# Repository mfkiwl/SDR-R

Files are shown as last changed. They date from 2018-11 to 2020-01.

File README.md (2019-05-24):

# SDR-R
Software Defined Radio Receiver(SDR-R) for UMBC Computer Engineering Capstone FA18-SP19

The purpose of this repository will be for tracking of source code changes/additions and team collaboration for the development of this SDR-R. This will facilitate in project organization and documentation.

__Note__: [The home for this repository can be found here](https://github.com/carrera1/SDR-R)

## Directories

__fpga-src/__

Source code for any/all HDL written for the FPGA.

__hw__

Directory for all files related to hardware

__sw-src/__

Source code for any/all C/C++, Matlab/Simulink, or Python code generated.

__vm-info/__

Relevant documentation pertaining to the software development environment is kept here (i.e. list of needed packages). 
This directory also includes an important readme file for setting up important dependencies on your machine. The code 
provided in **sw-src** should function on unix/linux style machines (to include macOS), as long as the relevant dependencies 
are available (mainly pthreads, libftdi, and libusb).

## Set up and Installation

__FPGA__

For any future capstone groups looking back on this, we apologize that the **fpga-src** directory is one of the less organized 
of the bunch. Of the blocks utilized, all but the Xilinx IP cores are here in this repository. These IP cores include a 
clock generator (which should be simple to set up) and a FIFO for interfacing the Rader ("link") block with the FSM 
handling the interfacing with the FTDI chip. The FPGA->FTDI FIFO should have a write width of 16 and a read width of 8. 
The FTDI->FPGA FIFO is written by use for handling the messages sent from the host computer to the FPGA. It is **not** meant 
for interfacing with the Rader block.

__Software__

Instructions for setting up your development environment can be found in **vm-info**. Please, follow the instructions there 
for setting up many of the minor dependencies needed for this project before continuing here.

This project has 2 major dependencies (each with their own sub-dependencies) that are critical for functionality:

* GNU Radio
  - Instructions for setting up found in **vm-info** directory
* libftdi
  - Open source library for writing code the interact with the FT232H bridge we're utilizing
  - Requires **libusb 1.0**, please install this on your system prior to installing libftdi
  - Requires **libconfuse**, please install this on your system prior to installing libftdi

### Installing libftdi

```bash
git://developer.intra2net.com/libftdi
cd libftdi
# READ THE READMEs IN YOUR FAVORITE TEXT EDITOR
```

The libftdi developers included *verbose* instructions within the repository you just cloned. Please read them thoroughly. 
They also include numerous examples demonstrating the functionality of the library, where this project drew heavily from the **stream-test.c**.

The libftdi developers also have their documentation available online which you may find necessary to understand how each 
function works and what their return values may be. [To save you time, you may find it here!](https://www.intra2net.com/en/developer/libftdi/documentation/group__libftdi.html)

Once both GNU Radio and libftdi are installed, software side set up is done. If the FPGA is properly set up, then you're good 
to compile and run the code found in **sw-src**.

## Acknowledgements

This project wouldn't be what it is without the inspiration drawn from the following:
* [This blog post](https://digibird1.wordpress.com/adc-readout-and-usb2-0-data-transfer-with-an-fpga/) for inspiring us to try out an FTDI chip instead of terrible terrible UART.
* [This github repo](https://github.com/RandomReaper/pim-vhdl) for providing an open source FSM for interfacing with the FT232H. Many thanks to [Mssr. Marc Pignat](https://github.com/RandomReaper)!

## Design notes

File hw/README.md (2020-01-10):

# Hardware Directory

All relevant files or documentation related to hardware should be kept here.

Please keep arrangement neat and logical for the sake of other people's sanity

When convenient or necessary, document this readme to explain the organization of this subdirectory

See other readmes as an example for consistant formatting

## Directories

__SDRR__

KiCad design files

__Chips__

Downloaded library files for IC's in schematic

__Datasheets__

Data sheets for the IC's

__FAB__

Output files from PCB design, for fabrication

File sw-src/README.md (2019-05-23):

# Software Source Directory

Source code for anything software related belongs here.
Please keep arrangement neat and logical for the sake of other people's sanity

When convenient or necessary, document this readme to explain the organization of this subdirectory

## About

__Interacting with SDR-R via USB__

The SDR-R is implemented on the Digilent cmod-a7 FPGA dev. board. Communication with host computer
is accomplished via an FTDI FIFO interface, specifically the FT232H in FT245 Synchronous FIFO mode.
 This project particularly uses the UM232H-B, however similar results could easily be had by using 
 any sort of FT232H based solution. The FT2232H would also be a viable alternative.

 Note that interacting with the SDR-R from the host computer will involve utilizing the open-source 
 libftdi libraries. Installation instructions may be provided in the future.
 Otherwise... google is a valuable tool.

## Directories

__demo-code__

The code contained here is effectively what was used for our final demo to 
Dr. LaBerge.

__maindriver__

The code contained here is what we consider our final driver code for this
project. Within this directory is the gnuradio flowgraph (.grc file) that
can be modified with added functionality by opening it in gnuradio-companion.
* compile.sh
  - idiot proof script for compiling the main driver code.
* flowgraph.grc
  - can be modified for added functionality by opening in gnuradio-companion
* INSTRUCTIONS.md
  - contains compilation instructions
* sdrdriver.c
  - main driver code. Requires libftdi, libusb, pthreads, among other things. 
  - Responsible for coordinating data transfer to/from the FTDI chip.
  - Creates a named pipe in /tmp/ during operation for holding IQ samples, this named pipe is removed when program closes.
  - **NOTE** There is a known race condition where the cleanup thread fails to terminate because the write operation which fills the named pipe is not successfully interrupted. Fortunately, if this occurs a simple Ctrl+C will send a second interrupt that will allow the program to close gracefully.
* top_block.py
  - This python script makes up the compiled gnuradio flowgraph. It is called as a child thread by the main driver.

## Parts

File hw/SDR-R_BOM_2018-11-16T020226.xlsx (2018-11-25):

Index | Quantity | Part Number | Manufacturer Part Number | Description | Customer Reference | Available | Backorder | Unit Price | Extended Price USD
1 | 3 | 296-35235-1-ND | ADC1175CIMTCX/NOPB | IC ADC 8BIT 20MHZ 85MW 24-TSSOP |  | 3 | 0 | 3 | 9.00
2 | 3 | SAM1121-32-ND | SSA-132-S-G | CONN RCPT .100" 32POS GOLD PCB |  | 3 | 0 | 5.04 | 15.12
3 | 3 | A97569-ND | 5-1634513-1 | CONN BNC JACK R/A 50 OHM PCB |  | 3 | 0 | 3.4 | 10.20
4 | 1 | 1286-1129-ND | 410-328 | BOARD CMOD A7-15T FPGA 48DIP |  | 1 | 0 | 75 | 75.00
5 | 10 | 311-49.9FRCT-ND | RC1206FR-0749R9L | RES SMD 49.9 OHM 1% 1/4W 1206 |  | 10 | 0 | 0.082 | 0.82
6 | 24 | 445-175206-1-ND | MLF2012A2R2JT000 | FIXED IND 2.2UH 50MA 500 MOHM |  | 24 | 0 | 0.223 | 5.35
7 | 10 | 1276-6330-1-ND | CIM21J202NE | FERRITE BEAD 2 KOHM 0805 1LN |  | 10 | 0 | 0.03 | 0.30
8 | 10 | 445-173302-1-ND | FG20X7S1H106KRT06 | CAP CER 10UF 50V X7S RADIAL |  | 10 | 0 | 0.975 | 9.75
9 | 3 | 296-18593-1-ND | SN74LVC8T245PWR | IC TRNSLTR BIDIRECTIONAL 24TSSOP |  | 3 | 0 | 1.05 | 3.15
10 | 3 | 296-16844-1-ND | SN74LVC1T45DCKR | IC TRNSLTR BIDIRECTIONAL SC70-6 |  | 3 | 0 | 0.6 | 1.80
11 | 3 | DESD5V0U1BA-7DICT-ND | DESD5V0U1BA-7 | TVS DIODE 5V 7.2V SOD323 |  | 3 | 0 | 0.29 | 0.87
12 | 100 | 445-14483-1-ND | C2012X6S1C106K085AC | CAP CER 10UF 16V X6S 0805 |  | 100 | 0 | 0.1466 | 14.66
13 | 10 | 1276-2589-1-ND | CL21C151GBANNNC | CAP CER 150PF 50V C0G/NP0 0805 |  | 10 | 0 | 0.16 | 1.60
14 | 3 | 1276-1305-1-ND | CL21C620JBANNNC | CAP CER 62PF 50V C0G/NP0 0805 |  | 3 | 0 | 0.1 | 0.30
15 | 10 | 311-110CRCT-ND | RC0805FR-07110RL | RES SMD 110 OHM 1% 1/8W 0805 |  | 10 | 0 | 0.047 | 0.47
16 | 3 | 987-1155-ND | 84WR10KLF | TRIMMER 10K OHM 0.25W SMD TOP |  | 3 | 0 | 2.54 | 7.62
17 | 10 | 1276-2698-1-ND | CL21C911JBCNNNC | CAP CER 910PF 50V C0G/NP0 0805 |  | 10 | 0 | 0.142 | 1.42
18 | 10 | 732-7857-1-ND | 885012007062 | CAP CER 680PF 50V C0G/NP0 0805 |  | 10 | 0 | 0.07 | 0.70
19 | 1 | SMDTCLF-ND | SMDTCLF | SOLDER TIP TINNER (ACTIVATOR) |  | 1 | 0 | 7.65 | 7.65
20 | 1 | TS391LT-ND | TS391LT | THERMALLY STABLE SOLDER PASTE NO |  | 1 | 0 | 16.95 | 16.95
21 | 3 | 296-26279-1-ND | OPA354AIDBVR | IC OPAMP VFB 100MHZ RRO SOT23-5 |  | 3 | 0 | 1.87 | 5.61
22 | 10 | LM2766M6X/NOPBCT-ND | LM2766M6X/NOPB | IC REG SWITCHD CAP 2VIN SOT23 |  | 10 | 0 | 0.912 | 9.12
23 | 100 | 399-1177-1-ND | C0805C104Z5VACTU | CAP CER 0.1UF 50V Y5V 0805 |  | 100 | 0 | 0.0289 | 2.89
24 | 3 | B120-FDICT-ND | B120-13-F | DIODE SCHOTTKY 20V 1A SMA |  | 3 | 0 | 0.37 | 1.11
25 | 3 | 296-27139-5-ND | UA78M05IDCY | IC REG LINEAR 5V 500MA SOT223-4 |  | 3 | 0 | 0.62 | 1.86
26 | 3 | 296-27140-5-ND | UA78M33CDCY | IC REG LIN 3.3V 500MA SOT223-4 |  | 3 | 0 | 0.58 | 1.74
27 | 3 | 493-10109-1-ND | UZR1C470MCL1GB | CAP ALUM 47UF 20% 16V SMD |  | 3 | 0 | 0.7 | 2.10
28 | 10 | 311-270CRCT-ND | RC0805FR-07270RL | RES SMD 270 OHM 1% 1/8W 0805 |  | 10 | 0 | 0.046 | 0.46
29 | 10 | 311-10KARCT-ND | RC0805JR-0710KL | RES SMD 10K OHM 5% 1/8W 0805 |  | 10 | 0 | 0.04 | 0.40

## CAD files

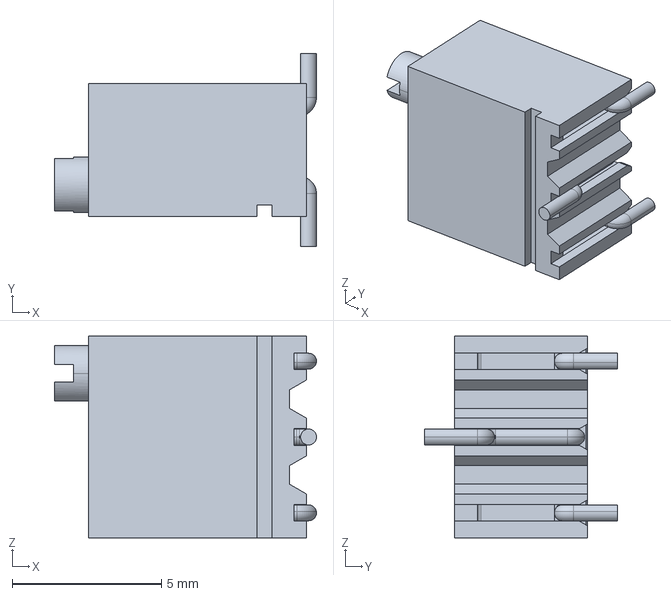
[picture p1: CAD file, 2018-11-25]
hw/Chips/84w.stp
8.78 x 6.48 x 6.76 mm

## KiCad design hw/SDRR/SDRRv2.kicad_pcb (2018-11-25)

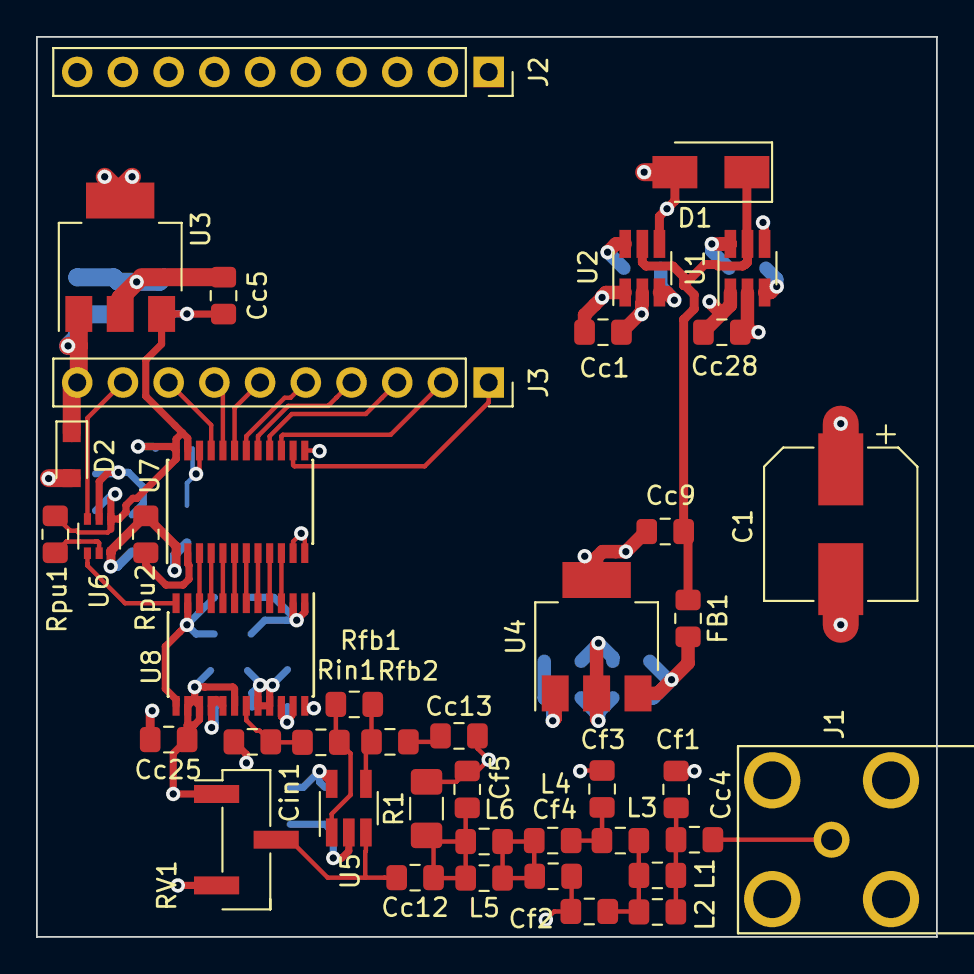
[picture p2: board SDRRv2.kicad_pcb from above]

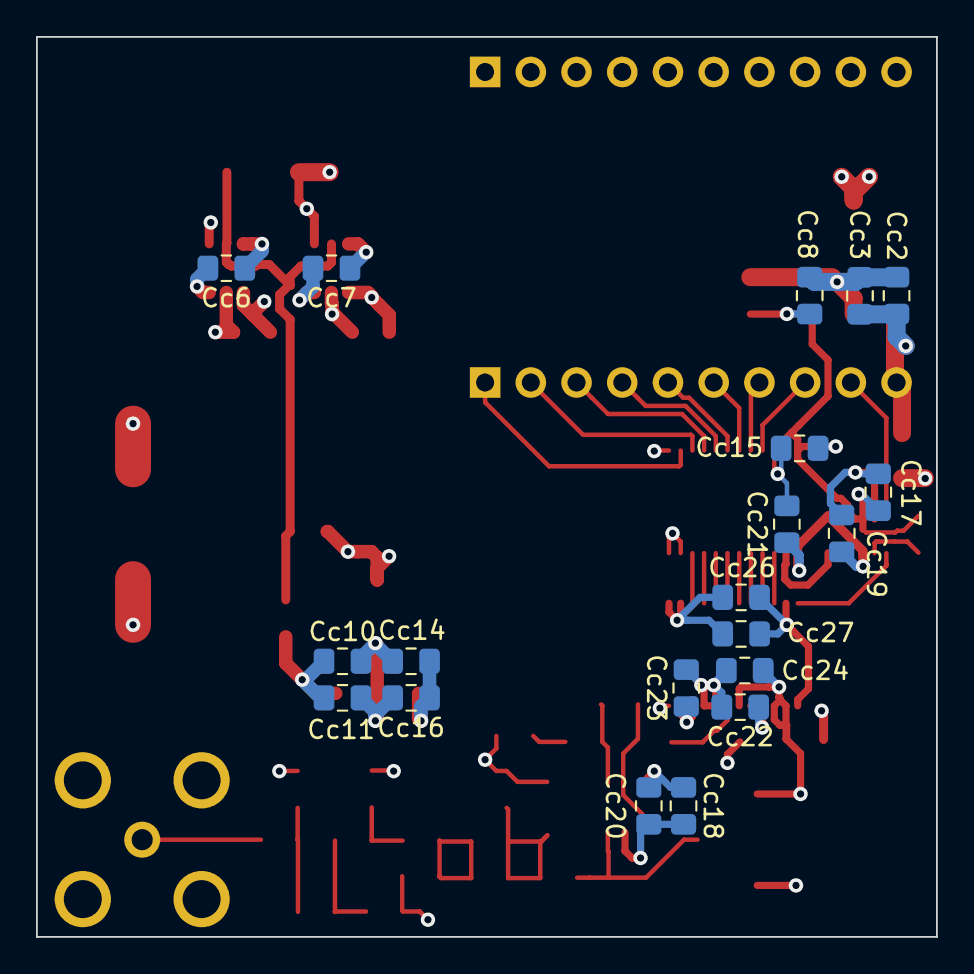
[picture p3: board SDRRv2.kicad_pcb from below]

Board: 4 copper layers, 50.0 x 50.0 mm, 62 parts (20 on the bottom side), 43 nets.

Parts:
C1: 47u; CP_Elec_8x6.2
Cc1, Cc3, Cc4, Cc5, Cc6, Cc7, Cc9, Cc10, Cc12, Cc13, Cc14, Cc15, Cc17, Cc18, Cc19, Cc21, Cc25, Cc27, Cc28: 10u; C_0805_2012Metric_Pad1.15x1.40mm_HandSolder
Cc2, Cc8, Cc11, Cc16, Cc20, Cc24, Cc26: 0.1u; C_0805_2012Metric_Pad1.15x1.40mm_HandSolder
Cc22, Cc23: 10uF; C_0805_2012Metric_Pad1.15x1.40mm_HandSolder
Cf1, Cf5: 150pF; C_0805_2012Metric_Pad1.15x1.40mm_HandSolder
Cf2, Cf4: 680pF; C_0805_2012Metric_Pad1.15x1.40mm_HandSolder
Cf3: 910pF; C_0805_2012Metric_Pad1.15x1.40mm_HandSolder
Cin1: 62pF; C_0805_2012Metric_Pad1.15x1.40mm_HandSolder
D1: B120-E3; D_SMA
D2: D_TVS; D_SOD-323_HandSoldering
FB1: L_Core_Ferrite; L_0805_2012Metric_Pad1.15x1.40mm_HandSolder
J1: Conn_Coaxial; TE_5-1634513-1
J2, J3: Conn_01x10_Female; PinSocket_1x10_P2.54mm_Vertical
L1, L2, L3, L4, L5, L6: 2.2u; L_0805_2012Metric_Pad1.15x1.40mm_HandSolder
R1: 50; R_1206_3216Metric_Pad1.42x1.75mm_HandSolder
RV1: R_POT; PinHeader_1x03_P2.54mm_Vertical_SMD_Pin1Left
Rfb1, Rfb2: 270; R_0805_2012Metric_Pad1.15x1.40mm_HandSolder
Rin1: 110; R_0805_2012Metric_Pad1.15x1.40mm_HandSolder
Rpu1, Rpu2: 10k; R_0805_2012Metric_Pad1.15x1.40mm_HandSolder
U1, U2: LM2766M6X_NOPB; SOT-23-6_Handsoldering
U3: UA78M33CDCY; SOT-223-3_TabPin2
U4: UA78M05IDCY; SOT-223-3_TabPin2
U5: OPA354AIDBVR; SOT-23-5_HandSoldering
U6: SN74LVC1T45DCK; SOT-363_SC-70-6
U7: SN74LVC8T245PWR; TSSOP-24_4.4x7.8mm_P0.65mm
U8: ADC1173; TSSOP-24_4.4x7.8mm_P0.65mm

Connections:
+3V3: Cc5.1, Cc8.1, Cc15.2, Cc17.1, Rpu1.1, U3.3, U6.1, U7.23, U7.24
+5V: C1.1, Cc1.1, Cc2.1, Cc3.1, Cc19.1, Cc21.1, Cc26.1, Cc27.1, Cc28.1, D1.2, D2.1, J3.10, Rpu2.1, U1.1, U1.4, U2.1, U2.4, U3.1, U6.6, U7.1, U8.11, U8.13
+5VA: Cc14.1, Cc16.1, Cc18.1, Cc20.1, Cc24.2, Cc25.2, RV1.1, U4.1, U5.5, U8.14, U8.15, U8.18
GNDREF: C1.2, Cc1.2, Cc2.2, Cc3.2, Cc5.2, Cc8.2, Cc9.2, Cc10.2, Cc11.2, Cc13.2, Cc14.2, Cc15.1, Cc16.2, Cc17.2, Cc18.2, Cc19.2, Cc20.2, Cc21.2, Cc22.2, Cc23.2, Cc24.1, Cc25.1, Cc26.2, Cc27.2, Cc28.2, Cf1.2, Cf2.2, Cf3.2, Cf4.2, Cf5.2, Cin1.2, D2.2, J1.2, J2.10, R1.2, RV1.3, U1.2, U2.2, U3.2, U4.2, U5.2, U6.2, U7.11, U7.12, U7.13, U7.22, U8.1, U8.2, U8.20, U8.21, U8.24
unnamed: Cc4.1, J1.1
unnamed: Cc4.2, Cf1.1, L1.1, L2.1
unnamed: Cc6.1, U1.6
unnamed: Cc6.2, U1.3
unnamed: Cc7.1, U2.6
unnamed: Cc7.2, U2.3
unnamed: Cc9.1, D1.1, FB1.1, U1.5, U2.5
unnamed: Cc10.1, Cc11.1, FB1.2, U4.3
unnamed: Cc12.1, Cf5.1, L5.2, L6.2, R1.1
unnamed: Cc12.2, RV1.2, U5.3
unnamed: Cc13.1, Rfb2.2
unnamed: Cc22.1, U8.16, U8.17
unnamed: Cc23.1, U8.22, U8.23
unnamed: Cf2.1, L1.2, L2.2, L3.1
unnamed: Cf3.1, L3.2, L4.1
unnamed: Cf4.1, L4.2, L5.1, L6.1
unnamed: Cin1.1, Rin1.2, U8.19
unnamed: J3.1, U7.14
unnamed: J3.2, U7.15
unnamed: J3.3, U7.16
unnamed: J3.4, U7.17
unnamed: J3.5, U7.18
unnamed: J3.6, U7.19
unnamed: J3.7, U7.20
unnamed: J3.8, U7.21
unnamed: J3.9, U6.3
unnamed: Rfb1.1, Rin1.1, U5.1
unnamed: Rfb1.2, Rfb2.1, U5.4
unnamed: Rpu1.2, U6.5
unnamed: Rpu2.2, U7.2
unnamed: U6.4, U8.12
unnamed: U7.3, U8.10
unnamed: U7.4, U8.9
unnamed: U7.5, U8.8
unnamed: U7.6, U8.7
unnamed: U7.7, U8.6
unnamed: U7.8, U8.5
unnamed: U7.9, U8.4
unnamed: U7.10, U8.3

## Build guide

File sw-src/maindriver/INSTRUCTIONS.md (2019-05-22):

# Introduction

The code contained here is intended for the Final Demo.

## Files

* flowgraph.grc
  - This may be edited via gnuradio-companion. When compiled in gnuradio-companion, it will generate top_block.py
* sdrdriver.c
  - This is **the** driver code for this demo.
* top_block.py
  - This is the gnuradio flowgraph that is invoked by sdrdriver

## Compilation Instructions

### Normal Way

```bash
gcc -Wall sdrdriver.c -lftdi1 -pthread -o runme.out
```
### Idiot Proof Way

```bash
./compile.sh
```

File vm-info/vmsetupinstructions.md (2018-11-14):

# Install VBox Additions
__NOTE__ 

The following is specifically instructions for the Debian Linux distribution. 
If you're using Ubuntu or Mint, this will maybe still work since they're based on 
Debian, but I can't promise
```bash
# Switch to root user
$ su
# Update APT database
$ apt-get update
# Then install security updates
$ apt-get upgrade
# Then install the following required packages for Virtualbox Guest Additions
$ apt-get install build-essential module-assistant
# Now configure system for building kernel modules
$ m-a prepare
# Do the Virtualbox thing to insert the guest additions CD
# then either cd as root into /media/cdrom1 or just navigate
# with the file explorer and open a root terminal in the directory
# Once there, run the following command
$ sh VBoxLinuxGuestAdditions.run
```
Pay close attention to the output, if there are any errors, try installing any/all 
of the packages in the following section (some/most should have been installed in 
the previous steps like gcc/g++/make/perl/etc.

After a reboot, you should now have a much better experience with your VM

## Want to SSH in? (Optional)
If you are using Debian and wish to SSH into your guest VM from your host computer:
1. Google how to add a 2nd "host-only" adapter 
2. [Do what they say here](https://unix.stackexchange.com/questions/37122/virtualbox-two-network-interfaces-nat-and-host-only-ones-in-a-debian-guest-on),
 or you may not have access to outside internet
 
## God, the default terminal colors hurt my eyeballs (Optional)
1. Edit -> Profile Preferences
2. In General tab, give your profile a name
3. In Colors tab, uncheck 'Use colors from system theme'
4. Under the same tab, select 'Solarized' from Built-in schemes drop down menu
5. Click ok
6. Edit -> Preferences
7. Click profiles tab, set your sexy profile as default by either deleting any other unnamed profiles, or using the drop down menu. I'm sure you can read.
8. Profit.

# Recommended Packages for Fresh Linux VM
* git
* gcc
* g++
* make
  - makefiles and whatnot
* libelf-dev
  - Required for OS class
* libqt4-dev
  - Needed for standard gui libraries
* libncurses5-dev
* libssl-dev
* perl
  - Needed for some build/compilation scripts
* pkg-config
* python and python-dev
  - 2.7 for GNU Radio, possibly 3 for other things
* pip
  - python package installer. Has loads of gnuradio libraries and is required.
  - May install via apt or [via these instructions](https://pip.pypa.io/en/stable/installing/)
* curl
  - Will be a dependency later on

# Installing GNU Radio

Review GNU radio by reading their Wiki. I'm building it from source *as you probably should too*, but it may
suffice for you to simply install the binaries and libraries via apt.

```bash
$ sudo apt-get install gnuradio
```

__NOTE__

If you install it this way, and end up having issues later on, I'm not going to help you... 
just apt-get remove it, and [install it via its source](https://wiki.gnuradio.org/index.php/InstallingGRFromSource)
like I did.

## Installing GNU Radio from Source

__SIDENOTE1__

GNU Radio currently is still mostly built on old Python 2.7 and is in the process of migrating to Python 3.
Unfortunately, we're not there yet so **make sure you have python and pip installed**.

__SIDENOTE2__

I wrote up the following steps as I completed them, and every step went perfect the first time around. Note that I am using Debian 9.5
as my base operating system. As you should be utilizing a VM... be smart about it all and take advantage of the **snapshots** 
capability that VirtualBox provides. I highly suggest creating one before starting the actual installation process at all.

1. Again, make sure you've installed python and pip. I linked to some instructions earlier, but if you're lazy 
[here they are again](https://pip.pypa.io/en/stable/installing/). Note that running get-pip.py will require root
priveleges or by specifying installing specifically to userspace with the proper '--user' flag.

2. Make sure pip is up to date before proceeding with the install
```bash
# If you previously installed pip with the --user flag,
#  You will have to do that every time you install or upgrade
#  a package you're managing via pip. For me, I would have to
#  prepend all these commands with sudo rather than using the
#  --user flag
$ [sudo] pip install -U pip
```

3. Using pip, we're going to install PyBOMBS. What is PyBOMBS? 
[Click here to find out more](https://www.gnuradio.org/blog/pybombs-the-what-the-how-and-the-why). 
I did a quick read through [of this](https://github.com/gnuradio/pybombs/blob/master/README.md) 
prior to installing, and there's some good stuff. All you really need to know at the moment
is that PyBOMBS is going to do all the heavy lifting for installing GNU Radio but you'll have
more time in a minute to read through it.
```bash
$ [sudo] pip install PyBOMBS
```

4. Once you have PyBOMBS successfully installed:
```bash
# NOTE: The installation process may go more smoothly if you allocate more than
#        two cores to your VM. If this isn't possible, then no worries.

# Apply a configuration (idk the particulars of what this really means)
$ pybombs auto-config
# Add the default recipes
$ pybombs recipes add-defaults
# Install gnuradio into your home directory ~/gr-prefix
$ pybombs prefix init ~/gr-prefix -a myprefix -R gnuradio-default
# Wait for last command to complete... go to the bathroom or something
# Or read the following which explains wth a prefix is
# Then if it's still working after you're done reading... leave your
#  laptop in the capstone lab or something and go to starbucks
# Seriously, it takes forever. If you see 'volk' being downloaded or built,
#  then you're on your last leg of the install
```
  - So what the heck is a prefix? Welp, it's the directory into which packages are installed.
  It may be `~/gr-prefix` like we specified in that last command, but it can be anything really.
  It should reside in your home directory so that it's easy to find and doesn't require admin
  rights to modify. Other developers out there may have multiple prefixes for their projects or w/e
  but we should be able to get by with just one. 
  - Prefixes require a configuration directory to function properly.
  Typically, it is called `.pybombs/` and is a subdirectory of the prefix.
  So, if your prefix is `~/gr-prefix`, there will be a directory called
  `~/gr-prefix/.pybombs/` containing special files. The two most important
  files are the inventory file (inventory.yml) and the prefix-local
  configuration file (config.yml), but it can also contain recipe files
  that are specific to this prefix.
  - Note that I'm not pulling all this info out of my ass, but putting it here for the lazy people
  who didn't click on [the previous link that I'm so kindly linking again](https://github.com/gnuradio/pybombs/blob/master/README.md)

5. Now you can run gnuradio-companion in one of two ways:
  - First set up the environment dictated by the packages installed into your prefix directory, and then run gnuradio-companion
  ```bash
  $ source ~/gr-prefix/setup_env.sh
  $ gnuradio-companion
  ```
  - Or use pybombs which I assume defaults to the default prefix which we specified earlier. I don't personally do it this way
  ```bash
  $ pybombs run gnuradio-companion
  ```
6. You have now installed the base gnuradio package from source!

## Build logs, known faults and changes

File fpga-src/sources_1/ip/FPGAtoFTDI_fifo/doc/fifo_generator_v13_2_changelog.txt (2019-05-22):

2018.2.2:
 * Version 13.2 (Rev. 2)
 * No changes

2018.2.1:
 * Version 13.2 (Rev. 2)
 * No changes

2018.2:
 * Version 13.2 (Rev. 2)
 * No changes

2018.1:
 * Version 13.2 (Rev. 2)
 * Bug Fix: Enable Safety Circuit option was unintentionally made available for user selection when Enable Reset Synchronization is not selected. This unintentional enablement is corrected and Enable Safety Circuit is available for user selection only if Enable Reset Synchronization option is selected
 * Bug Fix: REQP-1839 DRC warning removed from example test bench
 * Bug Fix: Read Data Count in behavioral model is updated to start with a valid value when Enable Reset Synchronization option is not selected
 * Other: As FIFO Generator core uses XPM_CDC module, user must ensure that the wr_rst and rd_rst overlap for at least C_SYNCHRONIZER_STAGE+1 slowest clock cycles if Enable Reset Synchronization option is disabled

2017.4:
 * Version 13.2 (Rev. 1)
 * Revision change in one or more subcores

2017.3:
 * Version 13.2
 * Feature Enhancement: Enable Safety Circuit option is made default for BRAM based FIFOs when Asynchronous Reset is selected
 * Feature Enhancement: All outputs are made synchronous to respective clock domain when Enable Safety Circuit option is selected
 * Feature Enhancement: All outputs are invalid for reset duration + 60 slowest clock cycles when Enable Safety Circuit option is selected
 * Feature Enhancement: All outputs are invalid for reset duration + 30 slowest clock cycles when Enable Safety Circuit option is not selected
 * Feature Enhancement: The outputs of FIFO Generator may be Xs for initial few clock cycles if the core is configured without reset. It is recommended to wait for 15 slowest clock cycles at the beginning of behavioral simulation (from time 0) before accessing the FIFO

2017.2:
 * Version 13.1 (Rev. 3)
 * No changes

2017.1:
 * Version 13.1 (Rev. 3)
 * Bug Fix: FIFO Generator core was constructing the buit-in FIFO sub-optimally for 2K-deep and 36-bit wide configuration. This is corrected to use the optimal FIFO structure
 * Bug Fix: In order to enable the tool to perform the recovery check on the reset, set_false_path for reset is kept only from the input port to the first flop where it connects to
 * Feature Enhancement: Updated the FIFO Generator's constraints to improve tool performance processing its XDC
 * Other: Internal device family change, no functional changes

2016.4:
 * Version 13.1 (Rev. 2)
 * Port Change: None
 * Bug Fix: Supported features table in the first page of GUI updated to reflect the asymmetry support for common clock BRAM FIFO
 * Feature Enhancement: None

2016.3:
 * Version 13.1 (Rev. 1)
 * Port Change: wr_rst_busy and rd_rst_busy ports made available if safety circuit is enabled
 * Bug Fix: Fixed issue which was causing the m_axis_tvalid to go high after the reset is released and no valid data written to the FIFO
 * Feature Enhancement: Safety circuit is made independent of Output Register and Enable Reset Synchronization options
 * Other: Added support for future devices
 * Other: Source HDL files are concatenated into a single file to speed up synthesis and simulation. No changes required by the user

2016.2:
 * Version 13.1
 * No changes

2016.1:
 * Version 13.1
 * Delivering only Verilog behavioral model.
 * Constraint(s) for Independent Clocks Distributed RAM FIFO is changed, which may issue a CDC-1 warning that can be safely ignored.
 * Output Register option is updated to offer either Embedded Register or Fabric Register or Both Embedded and Fabric Registers.
 * Updated the FIFO Generator GUI to provide Embedded Register option for Built-in FIFO when ECC mode in selected.
 * Programmable Full and Programmable Empty Threshold range has been reduced for UltraScale and UltraScale+ Built-in FIFO configurations. For more information on the exact threshold range change, refer the PG(057)
 * Programmable Full and Programmable Empty Threshold values were reset to its default values when the previous version of the core is upgraded to the latest version. This has been corrected

2015.4.2:
 * Version 13.0 (Rev. 1)
 * No changes

2015.4.1:
 * Version 13.0 (Rev. 1)
 * No changes

2015.4:
 * Version 13.0 (Rev. 1)
 * Fixed safety circuit related warnings in Behavioral model

2015.3:
 * Version 13.0
 * Additional safety circuit option provided for asynchronous reset configurations.
 * Delivering only VHDL behavioral model.
 * Added asymmetric port width support for 7-series Common Clock Block RAM FIFO
 * IP revision number added to HDL module, library, and include file names, to support designs with both locked and upgraded IP instances

2015.2.1:
 * Version 12.0 (Rev. 4)
 * No changes

2015.2:
 * Version 12.0 (Rev. 4)
 * No changes

2015.1:
 * Version 12.0 (Rev. 4)
 * Delivering  non encrypted behavioral models.
 * Enabled out-of-context clock frequency setting by adding FREQ_HZ parameter to clock ports
 * Enabling behavioral simulation for Built-in FIFO configurations changes the simulation file names and delivery structure.
 * Supported devices and production status are now determined automatically, to simplify support for future devices

2014.4.1:
 * Version 12.0 (Rev. 3)
 * No changes

2014.4:
 * Version 12.0 (Rev. 3)
 * Reduced DRC warnings.
 * Internal device family change, no functional changes
 * Encrypted source files are concatenated together to reduce the number of files and to reduce simulator compile time

2014.3:
 * Version 12.0 (Rev. 2)
 * Added support for Asynchronous AXI Stream Packet FIFO for UltraScale devices.
 * Added support for write data count and read data count for Asynchronous AXI Stream Packet FIFO for UltraScale devices.
 * Added support for write data count and read data count for Common Clock Block RAM FIFO when Asymmetric Port Width option is enabled for UltraScale devices.
 * Added support for Low Latency Built-in FIFO for UltraScale devices.

2014.2:
 * Version 12.0 (Rev. 1)
 * Repackaged to improve internal automation, no functional changes.

2014.1:
 * Version 12.0
 * Asynchronous reset port (rst) for Built-in FIFO configurations is removed for UltraScale Built-in FIFO configurations. When upgrading from previously released core, 'rst' port will be replaced by 'srst' port.
 * Synchronous reset (srst) mechanism is changed now for UltraScale devices. FIFO Generator will now provide wr_rst_busy and rd_rst_busy output ports. When wr_rst_busy is active low, the core is ready for write operation and when rd_rst_busy is active low, the core is ready for read operation.
 * Added asymmetric port width support for Common Clock Block RAM FIFO, Common Clock Built-in FIFO and Independent Clocks Built-in FIFO configurations for UltraScale Devices
 * Added 'sleep' input port for Common Clock Built-in FIFO and Independent Clocks Built-in FIFO configurations only for UltraScale Devices
 * Internal device family name change, no functional changes

2013.4:
 * Version 11.0 (Rev. 1)
 * Added support for Ultrascale devices
 * Common Clock Builtin FIFO is set as default implementation type only for UltraScale devices
 * Embedded Register option is always ON for Block RAM and Builtin FIFOs only for UltraScale devices
 * Reset is sampled with respect to wr_clk/clk and then synchronized before the use in FIFO Generator only for UltraScale devices

2013.3:
 * Version 11.0
 * AXI ID Tags (s_axi_wid and m_axi_wid) are now determined by AXI protocol type (AXI4, AXI3). When upgrading from previously released core, these signals will be removed when AXI_Type = AXI4_Full.
 * AXI Lock signals (s_axi_awlock, m_axi_awlock, s_axi_arlock and m_axi_arlock) are now determined by AXI Protocol type (AXI4, AXI3). When upgrading from previously released core, these signals width will reduce from 2-bits to 1-bit when AXI_Type=AXI4_Full
 * Removed restriction on packet size in AXI4 Stream FIFO mode. Now, the packet size can be up to FIFO depth
 * Enhanced support for IP Integrator
 * Reduced warnings in synthesis and simulation
 * Added support for Cadence IES and Synopsys VCS simulators
 * Improved GUI speed and responsiveness, no functional changes
 * Increased the maximum number of synchronization stages from 4 to 8. The minimum FIFO depth is limited to 32 when number of synchronization stages is > 4

2013.2:
 * Version 10.0 (Rev. 1)
 * Constraints processing order changed

2013.1:
 * Version 10.0
 * Native Vivado Release
 * There have been no functional or interface changes to this IP.  The version number has changed to support unique versioning in Vivado starting with 2013.1.

(c) Copyright 2002 - 2018 Xilinx, Inc. All rights reserved.

This file contains confidential and proprietary information
of Xilinx, Inc. and is protected under U.S. and
international copyright and other intellectual property
laws.

DISCLAIMER
This disclaimer is not a license and does not grant any
rights to the materials distributed herewith. Except as
otherwise provided in a valid license issued to you by
Xilinx, and to the maximum extent permitted by applicable
law: (1) THESE MATERIALS ARE MADE AVAILABLE "AS IS" AND
WITH ALL FAULTS, AND XILINX HEREBY DISCLAIMS ALL WARRANTIES
AND CONDITIONS, EXPRESS, IMPLIED, OR STATUTORY, INCLUDING
BUT NOT LIMITED TO WARRANTIES OF MERCHANTABILITY, NON-
INFRINGEMENT, OR FITNESS FOR ANY PARTICULAR PURPOSE; and
(2) Xilinx shall not be liable (whether in contract or tort,
including negligence, or under any other theory of
liability) for any loss or damage of any kind or nature
related to, arising under or in connection with these
materials, including for any direct, or any indirect,
special, incidental, or consequential loss or damage
(including loss of data, profits, goodwill, or any type of
loss or damage suffered as a result of any action brought
by a third party) even if such damage or loss was
reasonably foreseeable or Xilinx had been advised of the
possibility of the same.

CRITICAL APPLICATIONS
Xilinx products are not designed or intended to be fail-
safe, or for use in any application requiring fail-safe
performance, such as life-support or safety devices or
systems, Class III medical devices, nuclear facilities,
applications related to the deployment of airbags, or any
other applications that could lead to death, personal
injury, or severe property or environmental damage
(individually and collectively, "Critical
Applications"). Customer assumes the sole risk and
liability of any use of Xilinx products in Critical
Applications, subject only to applicable laws and
regulations governing limitations on product liability.

THIS COPYRIGHT NOTICE AND DISCLAIMER MUST BE RETAINED AS
PART OF THIS FILE AT ALL TIMES.

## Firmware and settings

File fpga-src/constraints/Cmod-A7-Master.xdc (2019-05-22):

## This file is a general .xdc for the CmodA7 rev. B
## To use it in a project:
## - uncomment the lines corresponding to used pins
## - rename the used ports (in each line, after get_ports) according to the top level signal names in the project

## 12 MHz Clock Signal
set_property -dict { PACKAGE_PIN L17   IOSTANDARD LVCMOS33 } [get_ports { sysclk }]; #IO_L12P_T1_MRCC_14 Sch=gclk
create_clock -add -name sys_clk_pin -period 83.33 -waveform {0 41.66} [get_ports {sysclk}];

## LEDs
#set_property -dict { PACKAGE_PIN A17   IOSTANDARD LVCMOS33 } [get_ports { led[0] }]; #IO_L12N_T1_MRCC_16 Sch=led[1]
#set_property -dict { PACKAGE_PIN C16   IOSTANDARD LVCMOS33 } [get_ports { led[1] }]; #IO_L13P_T2_MRCC_16 Sch=led[2]

## RGB LED
#set_property -dict { PACKAGE_PIN B17   IOSTANDARD LVCMOS33 } [get_ports { led0_b }]; #IO_L14N_T2_SRCC_16 Sch=led0_b
#set_property -dict { PACKAGE_PIN B16   IOSTANDARD LVCMOS33 } [get_ports { led0_g }]; #IO_L13N_T2_MRCC_16 Sch=led0_g
#set_property -dict { PACKAGE_PIN C17   IOSTANDARD LVCMOS33 } [get_ports { led0_r }]; #IO_L14P_T2_SRCC_16 Sch=led0_r

## Buttons
set_property -dict { PACKAGE_PIN A18   IOSTANDARD LVCMOS33 } [get_ports { BTNreset }]; #IO_L19N_T3_VREF_16 Sch=btn[0]
set_property -dict { PACKAGE_PIN B18   IOSTANDARD LVCMOS33 } [get_ports { fifo_reset }]; #IO_L19P_T3_16 Sch=btn[1]

## Pmod Header JA
#set_property -dict { PACKAGE_PIN G17   IOSTANDARD LVCMOS33 } [get_ports { Cbus0 }]; #IO_L5N_T0_D07_14 Sch=ja[1]
#set_property -dict { PACKAGE_PIN G19   IOSTANDARD LVCMOS33 } [get_ports { Cbus2 }]; #IO_L4N_T0_D05_14 Sch=ja[2]
#set_property -dict { PACKAGE_PIN N18   IOSTANDARD LVCMOS33 } [get_ports { ja[2] }]; #IO_L9P_T1_DQS_14 Sch=ja[3]
#set_property -dict { PACKAGE_PIN L18   IOSTANDARD LVCMOS33 } [get_ports { ja[3] }]; #IO_L8P_T1_D11_14 Sch=ja[4]
#set_property -dict { PACKAGE_PIN H17   IOSTANDARD LVCMOS33 } [get_ports { ja[4] }]; #IO_L5P_T0_D06_14 Sch=ja[7]
#set_property -dict { PACKAGE_PIN H19   IOSTANDARD LVCMOS33 } [get_ports { ja[5] }]; #IO_L4P_T0_D04_14 Sch=ja[8]
#set_property -dict { PACKAGE_PIN J19   IOSTANDARD LVCMOS33 } [get_ports { ja[6] }]; #IO_L6N_T0_D08_VREF_14 Sch=ja[9]
#set_property -dict { PACKAGE_PIN K18   IOSTANDARD LVCMOS33 } [get_ports { ja[7] }]; #IO_L8N_T1_D12_14 Sch=ja[10]

## Analog XADC Pins
## Only declare these if you want to use pins 15 and 16 as single ended analog inputs. pin 15 -> vaux4, pin16 -> vaux12
#set_property -dict { PACKAGE_PIN G2    IOSTANDARD LVCMOS33 } [get_ports { xa_n[0] }]; #IO_L1N_T0_AD4N_35 Sch=ain_n[15]
#set_property -dict { PACKAGE_PIN G3    IOSTANDARD LVCMOS33 } [get_ports { xa_p[0] }]; #IO_L1P_T0_AD4P_35 Sch=ain_p[15]
#set_property -dict { PACKAGE_PIN J2    IOSTANDARD LVCMOS33 } [get_ports { xa_n[1] }]; #IO_L2N_T0_AD12N_35 Sch=ain_n[16]
#set_property -dict { PACKAGE_PIN H2    IOSTANDARD LVCMOS33 } [get_ports { xa_p[1] }]; #IO_L2P_T0_AD12P_35 Sch=ain_p[16]
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

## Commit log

2018-11-25 PCB design
    Kicad design files
    Additional schematic libraries
    Gerber files as submitted for order
    Data sheets for IC's
    Digikey order PDF
    [84w.stp, SDR-R_BOM_2018-11-16T020226.xlsx, SDRR.kicad_pcb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]
2018-11-27 Added note for installing USB drivers for the FPGA
    There is a link embedded in the readme now that has a link to where you can download drivers for communicating serially with the FPGA.
2019-02-16 Add files via upload
    kHertz = 10;
    f = kHertz*1000; %in kHertz
    sampleFreq = 4*f; %in kHz
    sr = 1/sampleFreq;
    t = sr/2:sr:1-sr/2; %we have 1 seconds of samples in time
2019-03-04 Updated readme to reflect change from UART to FTDI FIFO
2019-05-15 Demo_broken_v1
    VHDL code implementing all components as of 5.15.19. Currently not working.
    Need to include the following IP cores:
    -Binary Counter. Ben used this for his clock generator
    -FIFO's for the state machine
    -Clk_wiz for both the 100/400 mhz clock.
    [Cmod-A7-Master.xdc]
